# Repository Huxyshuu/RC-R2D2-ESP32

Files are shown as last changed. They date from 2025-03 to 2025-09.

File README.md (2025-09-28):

#### Update (27.09.2025)
Fixed old image links for GitHub

R2D2 Poster

# Remote-Controlled R2D2
🚀 R2D2 Replica – Bluetooth-Controlled Droid with Web UI
This project brings R2D2 to life with **custom-designed, 3D-printed parts** and **Bluetooth control!** 
The droid is fully operable via a **PS4 controller**, allowing for smooth, responsive movement.

But that’s not all—a web-based interface lets you:

🎵 **Choose iconic R2D2 sound effects**

🔊 **Adjust volume levels** for a personalized experience

📡 **Monitor real-time status updates** as the droid moves and connects

Built from scratch, this project blends **electronics, CAD modeling, and programming** into a fully interactive experience.

[Link to Aalto's Wiki](https://wiki.aalto.fi/display/MEX/Remote-Controlled+R2D2)

# Table of Contents
1. [Video & Images](#video--images)
2. [Repository Organization](#repository-organization)
3. [Components](#components)
4. [Electronics](#electronics)
5. [CAD Models & 3D Prints](#cad-models--3d-prints)
6. [Web Interface](#web-interface)
7. [Code](#code)
8. [Future](#future)
9. [Thank You](#thank-you) ❤️

## Video & Images
Video and images taken from the Mechatronics Circus 2025 in Aalto University

https://github.com/user-attachments/assets/bc08d23b-32bb-44b7-bdc1-37275ab68ecd

Image1 from the Mechatronics Circus 2025
     Image2 from the Mechatronics Circus 2025

## Repository organization
The file structure will be as follows:
```
📦 RC-R2D2-ESP32
 ├─ 📄 README.md
 ├─ 📄 RoboCode.Ino
 ├─ 📄 webUI.html
 ├─ 📂 Prints (contains all the printable files in .STL format)
 │  ├─ 📄 torso.stl
 │  ├─ 📄 head.stl
 │  └─ ...
...
```

## Components
Most of the components are listed in the table with price estimates (shipping not included), however smaller components such as wires, resistors, bolts as well as 3D printed PLA parts are not listed. (**images are from online**)

<table>
  <tr>
     <th width="300">Adafruit HUZZAH32 – ESP32 Feather Board</th>
     <th width="300">MP2307 - Buck Regulator</th>
     <th width="300">DFR0299 - DFPlayer</th>
     <th width="300">MX1508 - DC Motor Driver</th>
  </tr>
  <tr>
      <td>ESP32</td>
      <td>MP2307</td>
      <td>DFR0299</td>
      <td>MX1508</td>
  </tr>
  <tr>
      <td><strong>30€</strong></td>
      <td><strong>2€</strong></td>
      <td><strong>3€</strong></td>
      <td><strong>2 X 6€</strong></td>
  </tr>
</table>

<table>
  <tr>
     <th width="300">ROB-12205 - GEARMOTOR 175 RPM</th>
     <th width="300">LSM-45F-8 Speaker</th>
     <th width="300">Round Rocker Switch</th>
     <th width="300">9V Battery</th>
  </tr>
  <tr>
      <td>ROB-12205</td>
      <td>LSM-45F-8</td>
      <td>Switch</td>
      <td>Battery</td>
  </tr>
  <tr>
      <td><strong>3 X 10€</strong></td>
      <td><strong>3€</strong></td>
      <td><strong>1€</strong></td>
      <td><strong>2 X 3.5€</strong></td>
  </tr>
</table>

<table>
  <tr>
     <th width="300">SD Card (8GB is more than enough)</th>
     <th width="300">PS4 Wireless Controller</th>
     <th width="300">Blue spray paint</th>
     <th width="300">Magnets (D: 10mm, h: 5mm)</th>
  </tr>
  <tr>
      <td>SD-Card</td>
      <td>PS4-controller</td>
      <td>Blue spray can</td>
      <td>Magnets</td>
  </tr>
  <tr>
      <td><strong>~8€</strong></td>
      <td><strong>~40€</strong></td>
      <td><strong>5€</strong></td>
      <td><strong>4 X 0.5€</strong></td>
  </tr>
</table>

The total cost of the components and accessories from the table comes to **98€ (+ 40€ Wireless Controller)** but to give some room for error, shipping and considering the parts not included such as 3D prints, bolts, wires, etc., rounding it up to **150-170€** range should probably cover everything. I have not tested other wireless bluetooth controllers with the code, so using anything other than PS4 controllers might require tweaking the code or using a completely different library to get it connected with the ESP.

## Electronics
I soldered all of the components to the protoboard as seen in the pictures. Most of the wires and connections are below the board and can't be seen from the camera images, but the wiring diagram should accurately show all details.

WiringWiringWiring

## CAD Models & 3D Prints
Custom 3D models to fit all the necessary electronics and components inside. I included a small hatch in the back to have easy access to electronics in case there's any need to update the code or a problem occurs. The whole build consists of 17 printed parts.

The branding will be removed from the hatch in the .STL files in case someone is interested in printing this ^^

R2D2 PosterR2D2 Poster
     
front viewside viewback viewup viewexploded view

WEB UI
## Web Interface
The illustration of the web interface that allows for more accessible control over the available settings as well as clunky movement commands. The ESP controller starts checking for a WiFi connection as soon as it is booted up. Pinging for 15 seconds while also blinking the WiFi LED. If the connection is found, it will send a telegram message containing the IP address to my telegram account. Accessing the IP address in any browser in the same network will show the web interface. If the pinging for a network fails, it will work just fine and continue without it, but there will be no access to the web interface and the additional settings provided there.

**The interface includes:**

**Movement ( turning the head, rotating and moving the body )**

**Sound control ( switching soundtracks, volume, mute )**

**And some information about the hardware ( IP, Controller battery, DFPlayer status...)**

## Code
### Instructions
In order to be able to boot the program onto the Adafruit ESP32 Feather board, **you have to change the partition scheme to a larger one**, which excludes the OTA and reduces the allocated memory for SPIFFS. This allows the app to be up to 3 MB, which is sufficient for this project. Picture below should help switching the switching in Arduino IDE.

Instructions

The full program contains over 1400 lines of code (mostly html). The program uses a few external libraries to achieve all the necessary functions such as connecting the PS4 controller to the ESP and running an asynchronous web server for additional controls. The **.ino file contains the entire program.** I have added a separate .html file, just to make it a bit easier to see and edit.

[Project code in Github](https://github.com/Huxyshuu/RC-R2D2-ESP32/blob/main/RoboCode.ino)

## Things to improvement
While most of the project came out as intended and worked smoothly, there are a few areas that would benefit from further improvement.

- The legs have a very flimsy attachment to the torso and are not rigid. Reworking the attachment would eliminate this problem.
- The head turns well with the current setup but creates a lot of noise from the edge of the head hitting the bearings. Removing the bearings from the torso and lifting the head up from the center beam in a rigid way should improve this.
- The middle leg is also attached to the torso in a rather silly way as well as having the caster wheel which makes the turning and climbing small bumps hard.

### Thank you
As with most "great" things, they are rarely done alone, so thank you to everyone who helped me and kept me company with this project.

Merihelinä Larimo

Paavo Miettinen

Szilard Papp

Johannes Malinen

& everyone involved

^^ ❤️

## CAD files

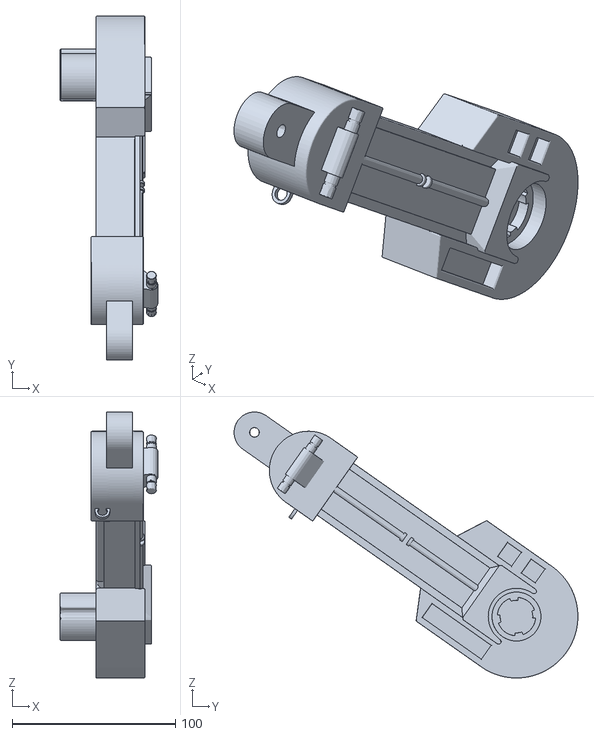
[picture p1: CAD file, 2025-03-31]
Prints/leg_right.stl
60.0 x 210.7 x 163.0

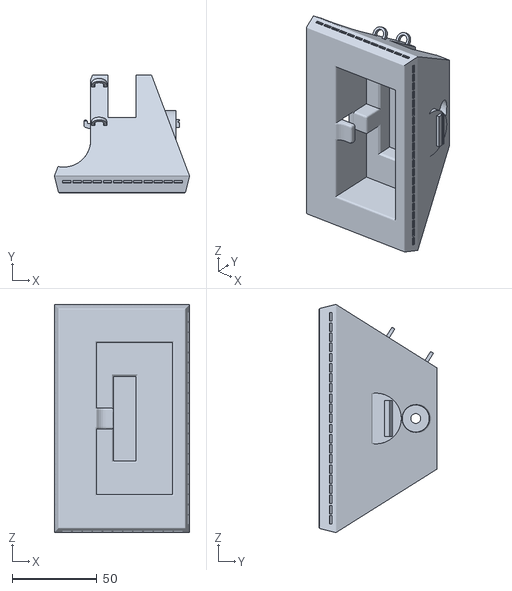
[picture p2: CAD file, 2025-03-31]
Prints/foot_left.stl
80.0 x 69.7 x 134.9

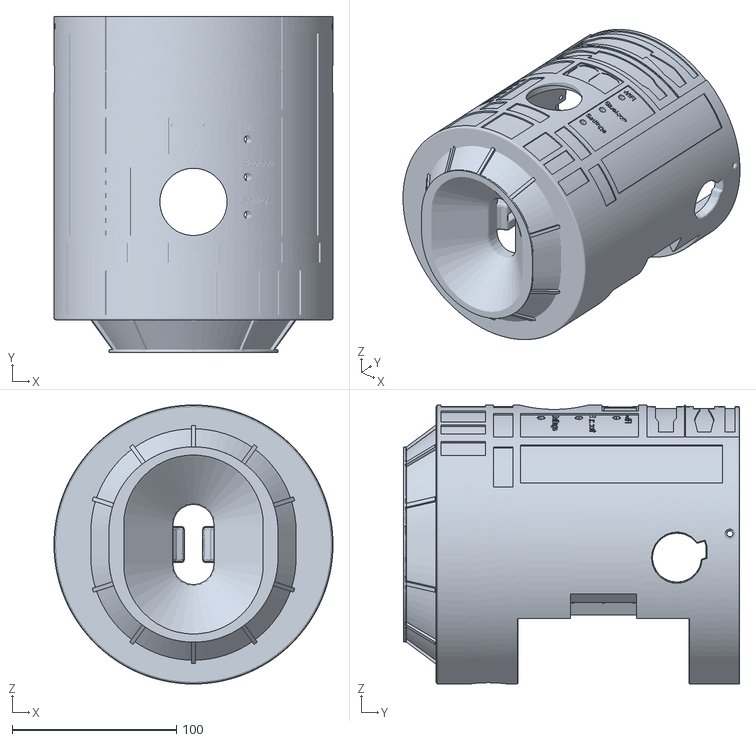
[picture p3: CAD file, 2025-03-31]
Prints/torso.stl
170.0 x 205.0 x 170.0

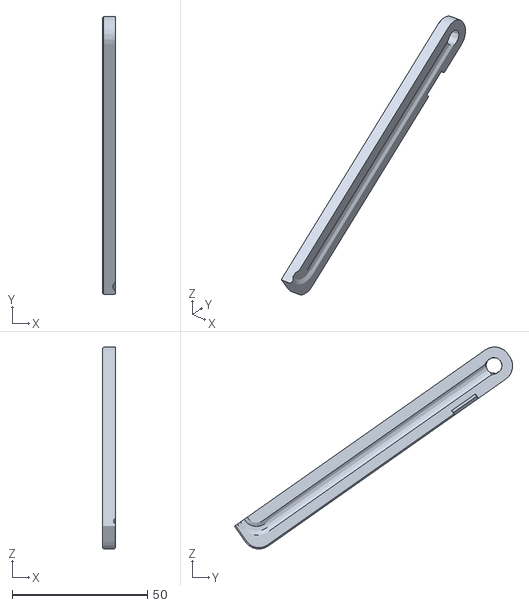
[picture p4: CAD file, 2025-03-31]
Prints/leg_lit_left.stl
4.90 x 102.8 x 74.6

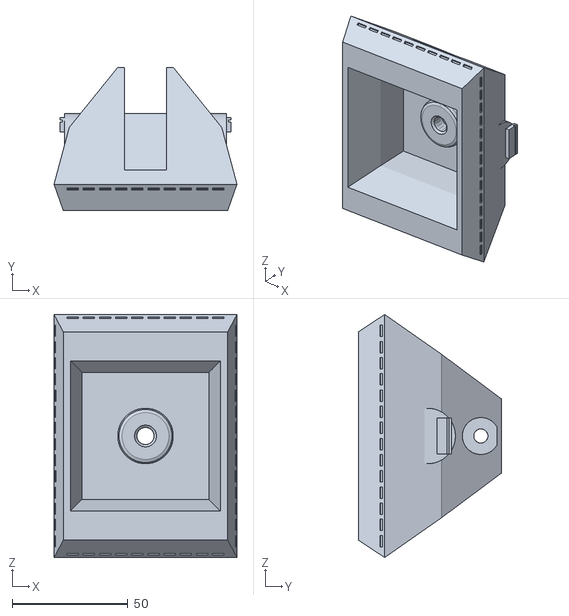
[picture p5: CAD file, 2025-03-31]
Prints/foot_mid.stl
79.2 x 62.0 x 105.2

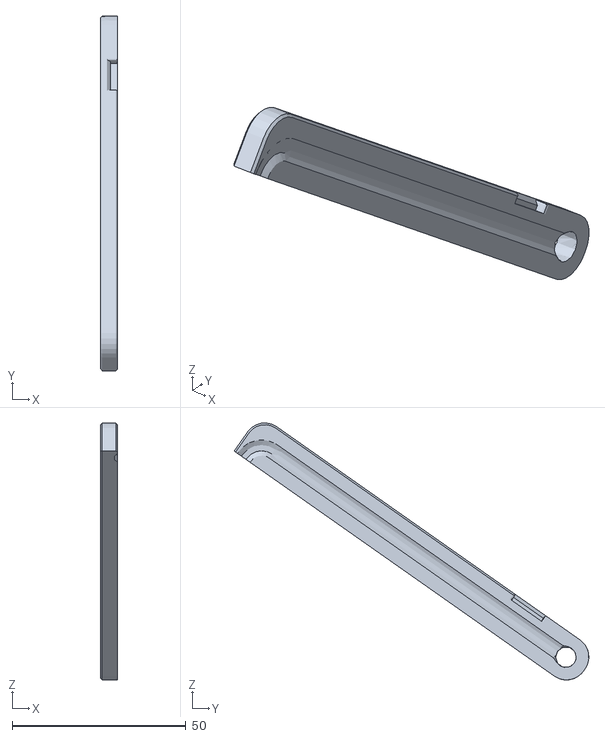
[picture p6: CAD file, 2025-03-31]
Prints/leg_lit_right.stl
4.90 x 102.2 x 74.0

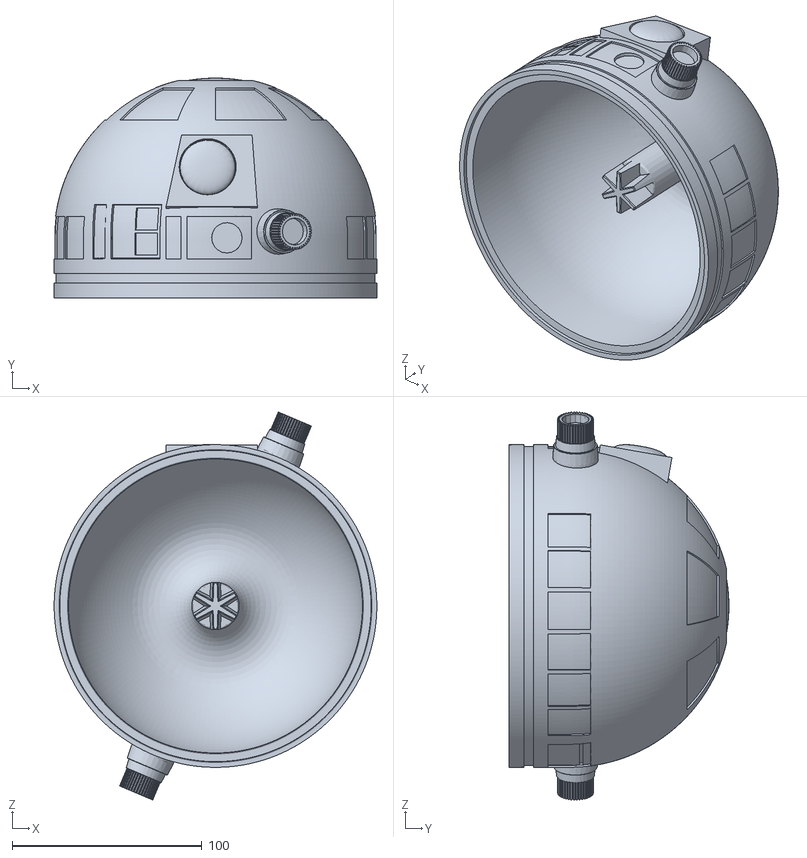
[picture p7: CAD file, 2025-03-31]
Prints/head.stl
170.0 x 115.9 x 204.4

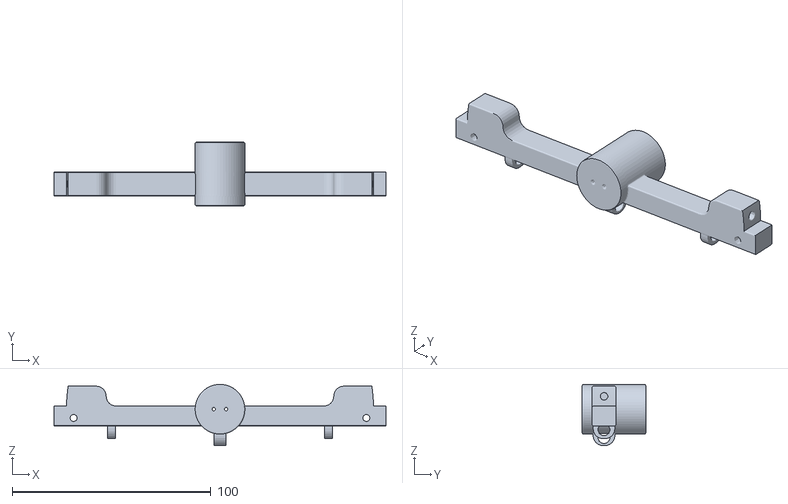
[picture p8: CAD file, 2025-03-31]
Prints/beam.stl
167.1 x 32.0 x 30.8

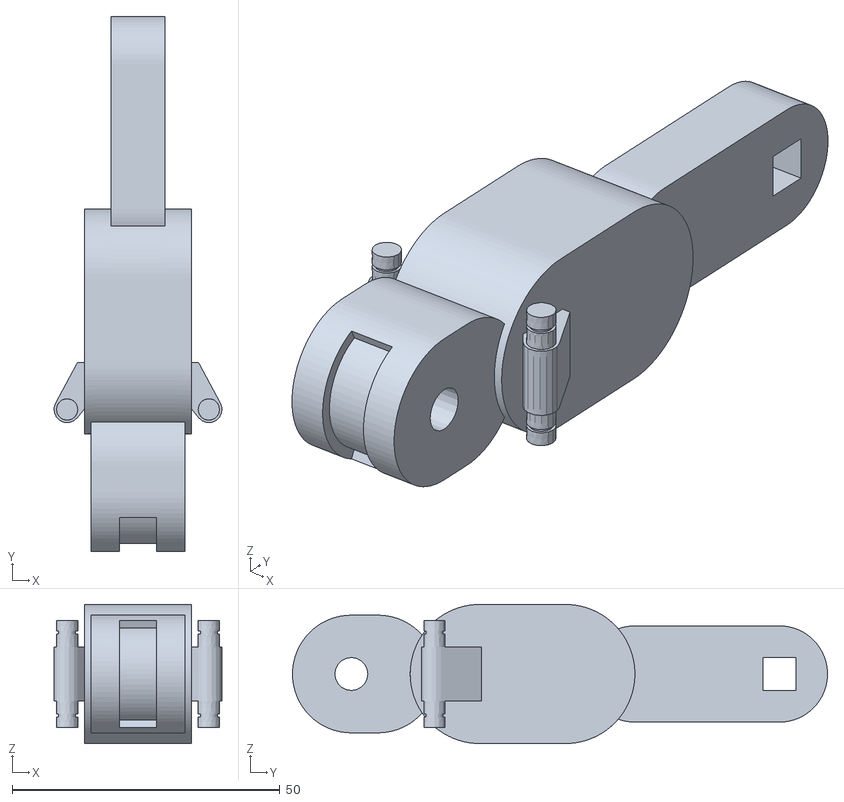
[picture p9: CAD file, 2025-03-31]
Prints/leg_mid.stl
31.4 x 100.0 x 26.0

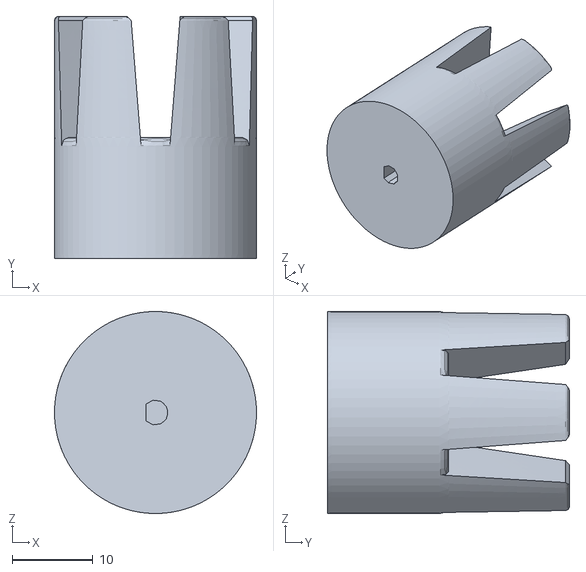
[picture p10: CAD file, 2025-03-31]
Prints/nozzle.stl
25.0 x 30.0 x 25.0

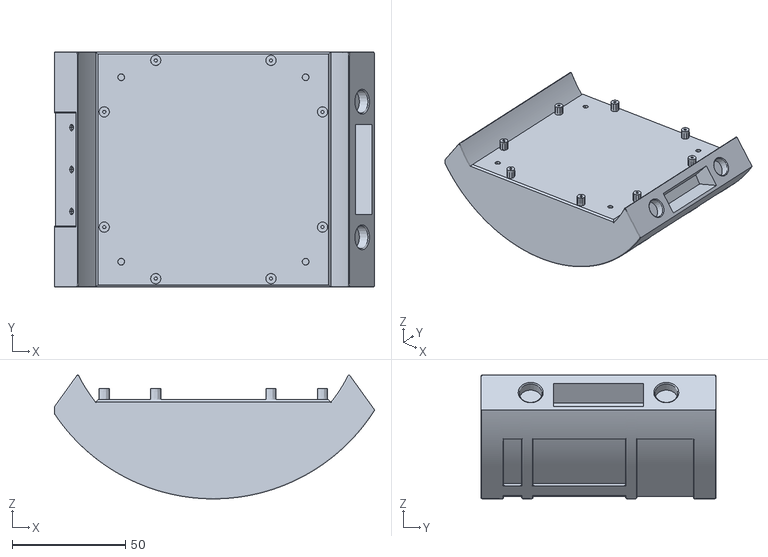
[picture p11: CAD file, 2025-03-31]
Prints/hatch.stl
141.6 x 104.0 x 54.8

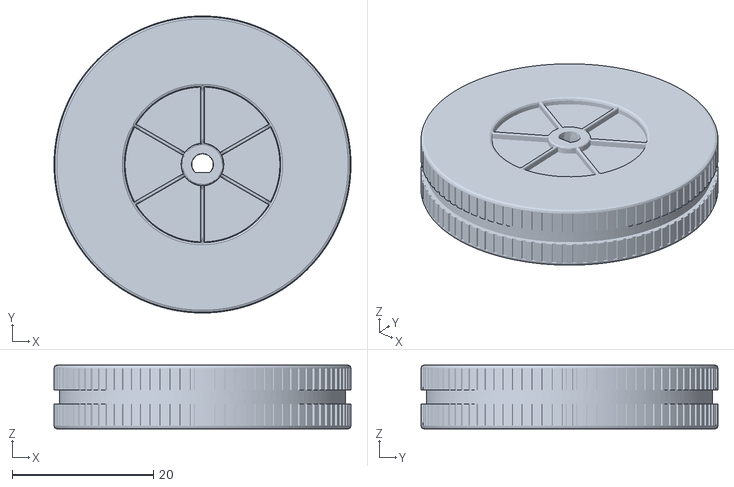
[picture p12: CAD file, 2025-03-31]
Prints/wheel.stl
42.0 x 42.0 x 9.00

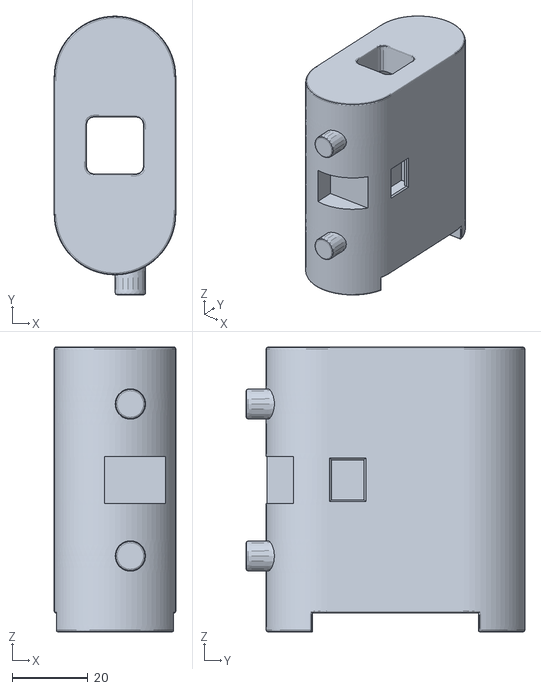
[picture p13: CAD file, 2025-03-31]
Prints/batteryholder_right.stl
32.0 x 73.3 x 75.0

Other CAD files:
Prints/leg_left.stl
Prints/foot_right.stl
Prints/batteryholder_left.stl

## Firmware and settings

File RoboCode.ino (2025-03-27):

#include <Bluepad32.h>
#include <WiFi.h>
#include <ESPAsyncWebServer.h>
#include "Arduino.h"
#include "DFRobotDFPlayerMini.h"
#include <HTTPClient.h>

// Telegram Bot Credentials
const char *botToken = "xxx";                                         // Replace with your bot token 
                                                                      // ( should look something like bot1111111111:AAAAA_-AAAAaAAaaAaAAaaaAAAAAAAAAAA ) 
const char *chatID = "xxx";                                           // Replace with your Telegram chat ID

// WiFi Credentials
const char *ssid = "xxx";                                             // Replace with your Wifi name
const char *password = "xxx";                                         // Replace with your Wifi password
AsyncWebServer server(80);

// Motor Control Pins
#define R_MOTOR_PWM1 15  
#define R_MOTOR_PWM2 33
#define L_MOTOR_PWM1 32  
#define L_MOTOR_PWM2 14
#define HEAD_MOTOR_PWM1 26  
#define HEAD_MOTOR_PWM2 25

// Status Indicator Pins
#define WIFI_PIN 27
#define SETTINGS_PIN 13
#define BT_PIN 12

// DFPlayer Serial Connection
HardwareSerial DFSerial(2);
DFRobotDFPlayerMini myDFPlayer;

// Controller Setup
ControllerPtr myControllers[BP32_MAX_GAMEPADS];

// System Variables
uint8_t battery = 0;
uint8_t volume = 25;
bool BTConnection = false;
bool DFConnection = false;
bool inSettings = false;
bool webControl = false;
bool muted = false;

String controllerModel = "Controller not connected";
String macAddress = "Error...";

uint8_t folderNum = 1;
uint8_t fileNum = 1;
int legSpeed = 0;
int headSpeed = 0;

unsigned long lastPlayTime = 0;
unsigned long playInterval = 0;

// Embedded HTML with CSS & JavaScript
const char index_html[] PROGMEM = R"rawliteral(
<!DOCTYPE html>
<html lang="en">
<head>
    <meta charset="UTF-8">
    <meta name="viewport" content="width=device-width, initial-scale=1.0">
    <title>R2D2 Controller</title>
    <link href="https://fonts.googleapis.com/css2?family=Inconsolata:wdth,wght@50..200,200..900&display=swap" rel="stylesheet">
    <style>
        :root {
            --primary-color: #eb9032;
            --secondary-color: #2D2E32;
            --hover-color: #835638;
            --active-color: #c07e52;
        }
    
        * {
            color: var(--primary-color);
            font-family: "Inconsolata", serif;
            font-optical-sizing: auto;
            font-style: normal;
            font-variation-settings: "wdth" 87.5;
        }

        body {
            text-align: center;
            background-color: var(--secondary-color);
            margin: 0;
        }

        h1 { font-weight: 300; }
        button {
            margin: 5px;
            font-size: 1em;
            border: none;
            outline: none;
        }

        #mainContainer {
            border: 2px solid var(--primary-color);
            margin: 0.5em;
            min-height: 100dvh; 
        }

        #mainDiv {
            display: flex;
            flex-wrap: wrap;
            justify-content: center;
            align-items: center;
            gap: 5em 15em;
            margin-top: 4em;
        }

        #leftDiv { width: 20em; }

        #rightDiv { width: 15em;}

        #r2s {
            height: 20em;
            position: relative;
        }

        #r2s .imgleg, #r2s .imghead {
            opacity: 0;
        }

        #r2s img {
            position: absolute;
            top: 0;
            left: 3em;
            height: 100%;
        }

        #controller { font-size: 1.2em; }
        #info {
            display: flex;
            flex-direction: column;
            align-items: flex-start;
            text-align: start;
            flex-wrap: wrap;
            gap: 0.1em;
        }

        .small-grid {
            display: flex;
            justify-content: space-between;
        }

        .grid-container {
            display: grid;
            grid-template-columns: repeat(3, 1fr);
            grid-template-rows: repeat(2, auto);
            gap: 0.5em;
        }

        .grid-item {
            padding: 1.2em;
            border-radius: 0.15em;
        }

        .gib {
            background-color: var(--primary-color);
            cursor: pointer;
        }
        .gib:hover { background-color: var(--hover-color); }
        .gib:active { background-color: var(--active-color); }
        .gib:focus { background-color: var(--active-color); }
        .flip { transform: scaleX(-1); }

        #sound {
            display: flex;
            flex-direction: column;
            justify-content: center;
            margin-top: 3em;
        }

        #sound p { font-size: 1.2em; }
        #sound button {
            background-color: var(--primary-color);
            cursor: pointer;
            padding: 1em;
            border-radius: 0.15em;
            color: var(--secondary-color);
            font-weight: 600;
        }
        #sound button:hover { background-color: var(--hover-color); }
        #sound button:active { background-color: var(--active-color); }
        #changeSound { margin-top: 2em;}

        /* Style the slider */
        #volumeSlider {
            -webkit-appearance: none; /* Remove default styling */
            appearance: none;
            height: 6px;
            background: var(--primary-color); /* Orange track */
            border-radius: 5px;
            outline: none;
            transition: background 0.3s;
        }

        /* Handle (thumb) */
        #volumeSlider::-webkit-slider-thumb {
            -webkit-appearance: none;
            appearance: none;
            width: 18px;
            height: 18px;
            background: #ff8c00; /* Darker orange thumb */
            border-radius: 50%;
            cursor: pointer;
            transition: background 0.3s;
        }

        #volumeSlider::-moz-range-thumb {
            width: 18px;
            height: 18px;
            background: #ff8c00;
            border-radius: 50%;
            cursor: pointer;
            transition: background 0.3s;
        }

        /* Hover effect */
        #volumeSlider:hover {
            background: #ff9500; /* Slightly darker orange */
        }

        #volumeSlider::-webkit-slider-thumb:hover {
            background: #ff7400; /* Even darker orange */
        }

        .folders { display: flex; justify-content: center; gap: 3em; margin-top: 0em;}
        .folder1, .folder2 { position: relative; cursor: pointer; width: 4em; height: 3.5em;}
        .folds { display: none; position: absolute; width: 100%; left: 0; top: 0;}
        .active { display: block; }

        #fileContainer1 { display: none; align-items: center; justify-content: center; flex-direction: column; margin-bottom: 10em;}
        #fileContainer2 { display: none; align-items: center; justify-content: center; flex-direction: column; margin-bottom: 10em;}
        #fileContainer3 { display: none; align-items: center; justify-content: center; flex-direction: column; margin-bottom: 10em;}
        .activeFlex { display: flex !important;}
        .files {
            display: flex;
            align-items: flex-end;
            height: 10em;
            width: 50%;
            padding: 2em;
            overflow-x: scroll;
            scrollbar-width: thin; /* Firefox */
            scrollbar-color: var(--primary-color) transparent; /* Firefox */
            z-index: 1;
        }

        /* For Webkit browsers (Chrome, Edge, Safari) */
        .files::-webkit-scrollbar {
            height: 6px;
        }

        .files::-webkit-scrollbar-track {
            background: var(--primary-color);
        }

        .files::-webkit-scrollbar-thumb {
            background: var(--primary-color);
            border-radius: 10px;
        }

        .files::-webkit-scrollbar-thumb:hover {
            background: var(--hover-color);
        }
        .file { display: flex; cursor: pointer;}
        .fileName { transform: translate(-3em, -3.5em) rotate(-45deg); z-index: 2; text-wrap: nowrap; width: 2em;}
        .circle { border-radius: 50%; border: 2px solid var(--primary-color); width: 3em; height: 3em;}
        .circle:hover { background-color: var(--primary-color);} .circle:hover p { color: var(--secondary-color);}
    </style>
    <script>
        var activeFolder = 0;
        var currentSound = { folder: 1, file: 1, name: "Scream" }
        let HeadLeftID, HeadRightID, UpID, DownID, LeftID, RightID;
        var muted = false;

        function updateBattery() {
            fetch('/battery')
                .then(response => {
                    if (!response.ok) {
                        throw new Error('Failed to fetch battery state');
                    }
                    return response.text();
                })
                .then(data => {
                    document.getElementById('battery').innerText = data;
                })
                .catch(error => {
                    console.error('Error fetching battery state:', error);
                    document.getElementById('battery').innerText = "Error...";
                });
        }

        function updateIP() {
            fetch('/ip')
                .then(response => {
                    if (!response.ok) {
                        throw new Error('Failed to fetch IP address');
                    }
                    return response.text();
                })
                .then(data => document.getElementById('ipAddress').innerText = data)
                .catch(error => {
                    console.error('Error fetching IP:', error);
                    document.getElementById('ipAddress').innerText = "Error...";
                });
        }

        function checkBTConnection() {
            fetch('/btcon')
                .then(response => {
                    if (!response.ok) {
                        throw new Error('Failed to fetch Bluetooth status');
                    }
                    return response.text();
                })
                .then(data => document.getElementById('BTConnection').innerText = data)
                .catch(error => {
                    console.error('Error fetching BT Status:', error);
                    document.getElementById('BTConnection').innerText = "Error...";
                });
        }

        function updateDFConnection() {
            fetch('/dfcon')
                .then(response => {
                    if (!response.ok) {
                        throw new Error('Failed to fetch DFPlayer status');
                    }
                    return response.text();
                })
                .then(data => document.getElementById('DFConnection').innerText = data)
                .catch(error => {
                    console.error('Error fetching DF Status:', error);
                    document.getElementById('DFConnection').innerText = "Error...";
                });
        }

        function updateModel() {
            fetch('/model')
                .then(response => {
                    if (!response.ok) {
                        throw new Error('Failed to fetch controller model');
                    }
                    return response.text();
                })
                .then(data => document.getElementById('model').innerText = data)
                .catch(error => {
                    console.error('Error fetching controller model:', error);
                    document.getElementById('model').innerText = "Error...";
                });
        }

        function updateMac() {
            fetch('/mac')
                .then(response => {
                    if (!response.ok) {
                        throw new Error('Failed to fetch MAC Address');
                    }
                    return response.text();
                })
                .then(data => document.getElementById('mac').innerText = data)
                .catch(error => {
                    console.error('Error fetching MAC Address:', error);
                    document.getElementById('mac').innerText = "Error...";
                });
        }

        function sendCommand(endpoint, params = "") {
            fetch(`/${endpoint}?${params}`)
                .then(response =>  {
                    if (!response.ok) {
                        console.error('Failed to send command:');
                    }
                })
                .catch(error => console.error('Error:', error));
        }

        function onTurnHead(dir) {
            sendCommand("turnHead", `dir=${dir}`);
        }

        function offTurnHead() {
            sendCommand("turnHead", "dir=stop");
        }

        function onMove(dir) {
            sendCommand("move", `dir=${dir}`);
        }

        function offMove() {
            sendCommand("move", "dir=stop");
        }

        function onTurn(dir) {
            sendCommand("turn", `dir=${dir}`);
        }

        function offTurn() {
            sendCommand("turn", "dir=stop");
        }



        function updateStatus() {
            checkBTConnection();
            updateModel();
            updateBattery();
            updateDFConnection();
            updateMac();
        }

        function checkLegs() {
            fetch('/legs')
                .then(response => {
                    if (!response.ok) {
                        throw new Error('Failed to fetch leg movement status');
                    }
                    return response.text();
                })
                .then(data =>{
                    let opacityValue = Math.min(Math.max(data / 255, 0), 1);
                    Array.from(document.getElementsByClassName('imgleg')).forEach(e => e.style.opacity = opacityValue);
                })
                .catch(error => {
                    console.error('Error fetching leg movement status:', error);
                    document.getElementById('model').innerText = "Error...";
                });
        };
        function checkHead() {
            fetch('/head')
                .then(response => {
                    if (!response.ok) {
                        throw new Error('Failed to fetch head movement status');
                    }
                    return response.text();
                })
                .then(data =>{
                    let opacityValue = Math.min(Math.max(data / 255, 0), 1);
                    Array.from(document.getElementsByClassName('imghead')).forEach(e => e.style.opacity = opacityValue);
                })
                .catch(error => {
                    console.error('Error fetching head movement status:', error);
                    document.getElementById('model').innerText = "Error...";
                });
        };

        function updateMovement() {
            checkLegs();
            checkHead();
        }

        function changeFolder(folderNum) {
            const folders = [1, 2, 3];
            
            folders.forEach(num => {
                const isActive = (num === folderNum);
                document.getElementById(`fold${num}fill`).classList.toggle("active", isActive);
                document.getElementById(`fold${num}`).classList.toggle("active", !isActive);
                document.getElementById(`fileContainer${num}`).classList.toggle("activeFlex", isActive);
            });

            activeFolder = folders.includes(folderNum) ? folderNum : 0;
        }

        function changeSound({ folder, file, name }) {
            currentSound = { folder: folder, file: file, name: name };
            document.getElementById('currentSound').innerText = `/0${folder}/${file.toString().padStart(3, '0')}.mp3 - ${name}`;

            fetch(`/changeSound?folder=${folder}&file=${file}`)
                .then(response => {
                    if (!response.ok) {
                        console.error('Failed to change sound:', response.status);
                    }
                })
                .catch(error => {
                    console.error('Error changing sound:', error);
                });
        }

        function playSound() {
            document.getElementById('playButton').innerText = "Playing...";

            fetch(`/playSound`)
                .then(response => {
                    if (!response.ok) {
                        console.error('Failed to play sound:', response.status);
                    }
                })
                .catch(error => {
                    console.error('Error playing sound:', error);
                });

            setTimeout(() => {
                document.getElementById('playButton').innerText = "Play sound";
            }, 2000);
        }

        function stopSound() {
            muted = !muted;
            if (muted) {
                fetch(`/stopSound`).catch(error => console.error('Error stopping sound:', error));
            }
        }

        function muteSound() {
            muted = !muted;
            if (muted) {
                fetch(`/muteSound`).catch(error => console.error('Error:', error));
                document.getElementById('muteButton').innerText = "Muted"
            } else {
                fetch(`/unmuteSound`).catch(error => console.error('Error:', error));
                document.getElementById('muteButton').innerText = "Mute"
            }
        }

        function changeVolume(volume) {
            fetch(`/setVolume?level=${volume}`).catch(error => console.error('Error:', error));
        }

        function changeVolumeHTML(volume) {
            document.getElementById('volumeValue').innerText = volume;
        }

        updateIP();

        setInterval(updateStatus, 1000);
        setInterval(updateMovement, 200);
    </script>
</head>
<body>
    <div id="mainContainer">
        <h1>R2D2 Controller</h1>

        <div id="mainDiv">
            <div id="leftDiv">
                <div id="r2s">
                    <img id="r2img"src="https://i.imgur.com/zJa6jQe.png" alt="R2D2">
                    <img class="imgleg" src="https://i.imgur.com/iss6W4f.png" alt="R2D2-left">
                    <img class="imgleg" src="https://i.imgur.com/fEttW5p.png" alt="R2D2-right">
                    <img class="imghead" src="https://i.imgur.com/6LFWx3D.png" alt="R2D2-head">
                </div>
                <p id="controller">Bluetooth Controller:<br><strong id="BTConnection">Loading...</strong></p>
                <div id="info">
                    <p>Controller Battery: <strong><span id="battery">Controller not connected</span></strong></p>
                    <p>Controller Model: <span id="model">Controller not connected</span></p>
                    <p>ESP Mac Address: <span id="mac">Loading...</span></p>
                    <p>IP Address: <span id="ipAddress">Loading...</span></p>
                    <p>DF Player: <span id="DFConnection">Loading...</span></p>
                </div>
            </div>

            <div id="rightDiv">
                <div>
                    <div>
                        <p>Head</p>
                        <div class="small-grid">
                            <div onmousedown="onTurnHead('left')" onmouseup="offTurnHead()" class="grid-item gib"><svg xmlns="http://www.w3.org/2000/svg" width="24" height="24" viewBox="0 0 24 24"><g fill="none" stroke="#2D2E32" stroke-linecap="round" stroke-linejoin="round" stroke-width="3"><path d="m8 5l-5 5l5 5"/><path d="M3 10h8c5.523 0 10 4.477 10 10v1"/></g></svg></div>
                            <div onmousedown="onTurnHead('right')" onmouseup="offTurnHead()" class="grid-item gib flip"><svg xmlns="http://www.w3.org/2000/svg" width="24" height="24" viewBox="0 0 24 24"><g fill="none" stroke="#2D2E32" stroke-linecap="round" stroke-linejoin="round" stroke-width="3"><path d="m8 5l-5 5l5 5"/><path d="M3 10h8c5.523 0 10 4.477 10 10v1"/></g></svg></div>
                        </div>
                    </div>
                    <div>
                        <p>Body</p>
                        <div class="grid-container">
                            <div class="grid-item"></div>
                            <div onmousedown="onMove('forward')" onmouseup="offMove()" class="grid-item gib"><svg xmlns="http://www.w3.org/2000/svg" width="24" height="24" viewBox="0 0 24 24"><path fill="none" stroke="#2D2E32" stroke-linecap="round" stroke-linejoin="round" stroke-width="3" d="M12 20V4m-7 7l7-7l7 7"/></svg></div>
                            <div class="grid-item"></div>
                            <div onmousedown="onTurn('left')" onmouseup="offTurn()" class="grid-item gib"><svg xmlns="http://www.w3.org/2000/svg" width="24" height="24" viewBox="0 0 24 24"><path fill="none" stroke="#2D2E32" stroke-linecap="round" stroke-linejoin="round" stroke-width="3" d="m11 5l-7 7l7 7m-7-7h16"/></svg></div>
                            <div onmousedown="onMove('backward')" onmouseup="offMove()" class="grid-item gib"><svg xmlns="http://www.w3.org/2000/svg" width="24" height="24" viewBox="0 0 24 24"><path fill="none" stroke="#2D2E32" stroke-linecap="round" stroke-linejoin="round" stroke-width="3" d="M12 20V4m-7 9l7 7l7-7"/></svg></div>
                            <div onmousedown="onTurn('right')" onmouseup="offTurn()" class="grid-item gib"><svg xmlns="http://www.w3.org/2000/svg" width="24" height="24" viewBox="0 0 24 24"><path fill="none" stroke="#2D2E32" stroke-linecap="round" stroke-linejoin="round" stroke-width="3" d="M4 12h16m-7-7l7 7l-7 7"/></svg></div>
                        </div>
                    </div>
                </div>
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
void loop() {
  if (BP32.update())
    processControllers();

  delay(150);

  if (myDFPlayer.available()) {
    printDetail(myDFPlayer.readType(), myDFPlayer.read());  //Print the detail message from DFPlayer to handle different errors and states.
  }

  playRandomFile();
}

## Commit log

2025-03-31 Added a prints folder
    [batteryholder_left.stl, batteryholder_right.stl]
2025-03-31 Added all print files
    [beam.stl, foot_left.stl, foot_mid.stl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]
